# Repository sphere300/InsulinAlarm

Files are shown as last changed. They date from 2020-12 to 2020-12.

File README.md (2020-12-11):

# InsulinAlarm
A quick and dirty project to build a small device that sounds an alarm if the insulin is left out of the fridge too long.

# Part List:
* [Adafruit Trinket M0](https://www.adafruit.com/product/3500)
* [MCP9808 High Accuracy I2C Temperature Sensor Breakout Board](https://www.adafruit.com/product/1782)
* [Piezo Buzzer - PS1240] (https://www.adafruit.com/product/160)
* [Lithium Ion Polymer Battery - 3.7v 500mAh] (https://www.adafruit.com/product/1578)
* [JST-PH 2-Pin SMT Right Angle Connector] (https://www.adafruit.com/product/1769)
* Wire
* Snap Safe Safety Amber Vial 40 DR (Could be replaced with any large enough container though you would need to change one of the prints)

This project also assumes that you have a Lantus Insulin vial inside a Snap Safe Safety Amber Vial 40 DR container. The electronics can easily fit within the 40DR saftey vial with the insulin.

# Assembly Instructions:
*Desolder the DotStar LED, and the on LED.* 

With those two LEDs you are looking at a battery life with a 500 mAh battery in the neighborhood of 20 days. Without them it will last up to 347.22 days (realistically a lot less, but that's the theoretical cap with a 500 mAh battery).

The DotStar has a high idle current somewhere in the neighborhood of 1 mA. Without it and the on LED I was able to measure a standby current from the battery of 0.06 mA

I suggest you do this first as there is a very real chance you will break and destroy your Trinket M0 in the process of removing the SMT LED's. The good new is that they are cheap microcontrollers so it won't set you back much but its a tricky process. After removing the LEDs you should immediately test using a blink demo to ensure that after their removal there are no shorts and that the code is able to run.

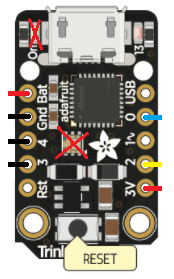
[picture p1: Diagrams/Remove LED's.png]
LED's to Remove


Once you have the LED's removed you should proceed to wire everything up:

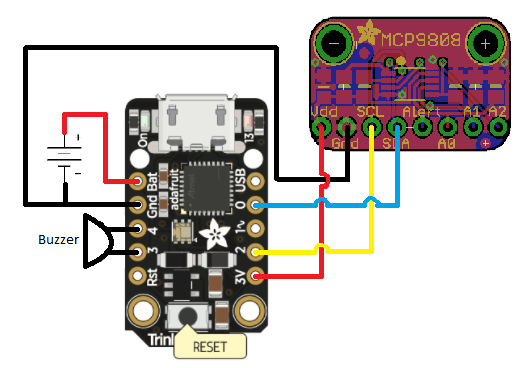
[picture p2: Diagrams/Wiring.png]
Wiring Diagram


Note in the parts list I list a 500 mAh battery but in the code I mention a 420 mAh battery that is because I used the 420 with a [JS Battery Extender Cable] (https://www.adafruit.com/product/1131) on my iteration. In retrospect the right angle JST connecter would have been better as cutting the cable and soldering a female connector to the short wire 420 mAh battery is tad fragile.

Once everything is wired you can snap it all together for something like this:

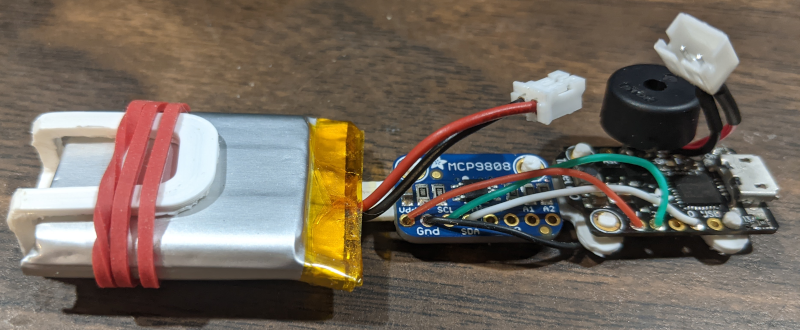
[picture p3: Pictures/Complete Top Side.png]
Finished Top Side

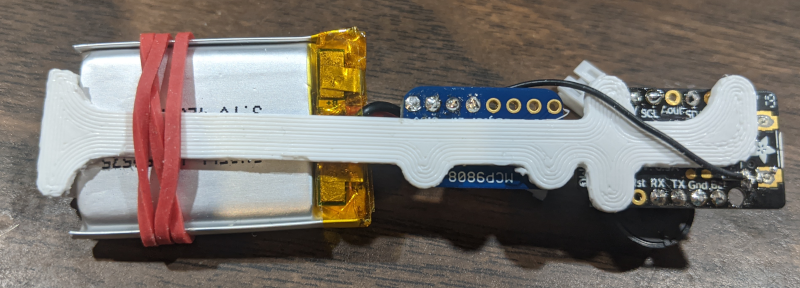
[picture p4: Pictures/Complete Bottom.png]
Finished Bottom Side


Push the assembly into the pill bottle and then put the electronics inside.

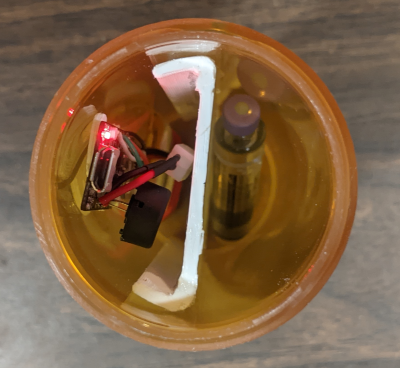
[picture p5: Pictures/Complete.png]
All Together


One last todo I may update in the coming days is to firmely attach the electronics and battery to the seperator as they move around a bit when I remove the insulin. As I mentioned in my description I recently bought the new lantus so I just wanted something quick and dirty. I am certain as I use it I will tweak and adjust this as I continue to give insulin to my cat twice daily but overal this is the first iteration of this.

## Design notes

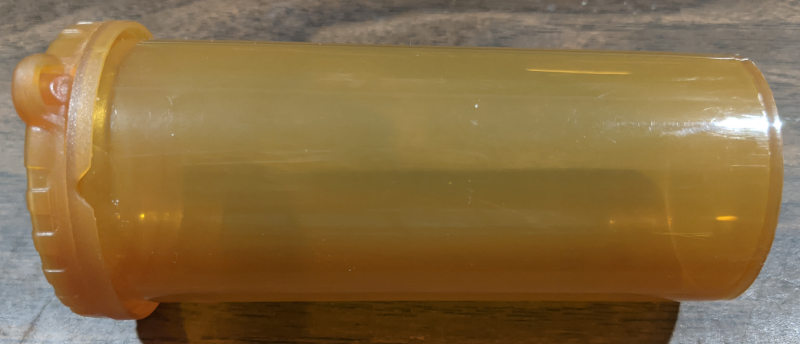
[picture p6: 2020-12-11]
Pictures/Snap Safe Safety Amber Vial.png

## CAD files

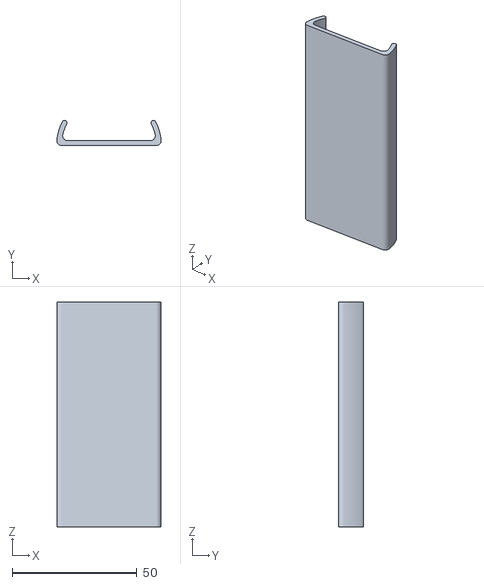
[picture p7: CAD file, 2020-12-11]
3D Models/PillBottleHolder.stl
41.8 x 10.1 x 90.0

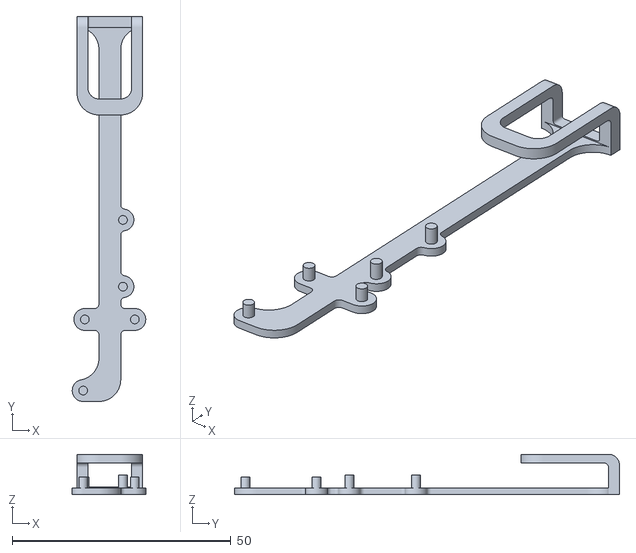
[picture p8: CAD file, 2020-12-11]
3D Models/Insulin Alarm.stl
16.8 x 88.0 x 9.25

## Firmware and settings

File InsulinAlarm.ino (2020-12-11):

/*

  Insulin Alarm Code

  This code is intended to be a very quick and dirty insulin alarm that goes off if the container it is stored in is left outside of the fridge too long. 
  
  I have a cat who is now diabetic, and after leaving the insulin out of the fridge one too many times by accident I decided to makee this alarm so that I don't need to keep buying more insulin.

  This is a very simple set of code designed to work with the adafruit trinket M0 board, a MCP9808 temperature sensor on adafruits break out board, a lithium ion battery, and a simple PS1240 Buzzer.
  
  Created by Sphere300

  Warnings and disclaimers:
  I am not an expert at firmware or hardware design and everything I do in the code and with the hardware may be flawed, so use this code and hardware at your own risk.
  
  This is a hobby project and is shared with others in case they find it useful. This code is not exensivly tested and may fail unexpectedly for any reason, 
  and as such it is NOT intended to be used in a medical setting or in any scenario where its failure may cause harm or loss of life.

  License:
  All materials for this project are released under te GNU Lesser General Public License 2.1. The Adafruit MCP9808 Library uses an MIT license and the RTCZero library is also GNU Lesser Publc license 2.1.
  You can find their work hosted in the arduino libraries or on git hub:
  https://github.com/arduino-libraries/RTCZero
  https://github.com/adafruit/Adafruit_MCP9808_Library

  This code was initially based on the SimpleRTCAlarm demo included with the RTC Libary.

  This code was created on:
  December 11 2020  
   
*/

#include <RTCZero.h>
#include "Adafruit_MCP9808.h"

Adafruit_MCP9808 tempsensor = Adafruit_MCP9808();

/* Create an rtc object */
RTCZero rtc;

//Buzzer bins
int buzzer1 = 3;
int buzzer2 = 4;

//Build in Red LED (the one we did not desolder)
int led = 13;

//Some time constants to setup the RTC
/* Change these values to set the current initial time */
const byte seconds = 0;
const byte minutes = 00;
const byte hours = 17;
/* Change these values to set the current initial date */
const byte day = 17;
const byte month = 11;
const byte year = 15;

//Track how long we have been on os we can indicate when we need to recharge the battery.
long onCount = 0;

void setup()
{
  //Indicate we are ready to program
  digitalWrite(led, HIGH);

  //Delay for 60 seconds to let us reprogram it if we need to (Standby screws up the USB avr)
  delay(60000); //Let us reprogram the board before we put the board to sleep.

  //
  digitalWrite(led, LOW);

  //Ensure we can talk to the temperature sensor
  if (!tempsensor.begin(0x18)) {
    
    //If we can't measure temperature then we are not going anywhere fast.
    while (1)
    {
      //Pulse the LED to let us know it can't talk to the Temp Sensor.
      digitalWrite(led, HIGH);
      delay(1000);
      digitalWrite(led, LOW);
      delay(1000);
    }
  }
  //Choose the fastest temperature setting with +-0.5°C in 30 ms
  tempsensor.setResolution(0); 
  //Shut it down to save power
  tempsensor.shutdown_wake(1);

  //Setup the buzzer
  pinMode(buzzer1, OUTPUT); 
  pinMode(buzzer2, OUTPUT);
  //Set the buzzer off
  digitalWrite(buzzer1, LOW);
  digitalWrite(buzzer2, LOW);
  
  //Start up the clock
  rtc.begin();
  rtc.setTime(hours, minutes, seconds); //We have no idea what the real time is ... 
  rtc.setDate(day, month, year);
  //Set the first alarm to be 1 minute from now 
  rtc.setAlarmTime(17, 05, 00);
  rtc.enableAlarm(rtc.MATCH_HHMMSS);
  rtc.attachInterrupt(alarmMatch);
  //Got to sleep.
  rtc.standbyMode();
  

}

void loop()
{
  onCount += 1;
  //Assuming a 420 mAh and based on standby consumption with the Dotstar and On LED's removed (0.06 mA) we should have an ideal longevity of about 291.7 days,
  // but we are chilling battery, it will lose power over time, and it may not be fully charged so lets turn on the low batt after 75% of the expected life or 218.75 days. 
  //The board will be asleep most of the time unless you leave it outside the fridge, so we assume that the standby dominates the power consumption. 
  //Based on that We can make an assumption that each sleep wake cycle dominates the on time. 
  //Ignoring the roughly 30ms per sleep cycle this we get 63000 cycles of 5 minute sleeps before 75% of the ideal battery life is consumed.
  if (onCount > 63000) {
    // Turn on to indicate low battery, yes it will consume power but without it we will never know when to replace the battery, and in theory you will use the insulin every day. 
    digitalWrite(led, HIGH);
  }
  
  //Wakeup the temperature sensor:
  tempsensor.wake();   // wake up, ready to read!
  //Read the temp
  float c = tempsensor.readTempC();
  while (c > 16)
  {
    //If the temp is > 16 then start buzzing. In theory it should be colder so this will turn off faster when its put back in the fridge.
    //buzz for 10 seconds
    for (int j = 0; j <= 50; j++) { //Buzz for 10 seconds.
      for (int i = 0; i <= 50; i++) {
        //Make a square wave. Set the pins to opposite values to give us a bit more sound
        digitalWrite(buzzer1, HIGH);
        digitalWrite(buzzer2, LOW);
        delay(1);               
        digitalWrite(buzzer1, LOW);
        digitalWrite(buzzer2, HIGH);
        delay(1);
      }
      for (int k = 0; k <= 100; k++) {
        //Make a higher pitched square wave
        digitalWrite(buzzer1, HIGH);
        digitalWrite(buzzer2, LOW);
        delay(0.5);
        digitalWrite(buzzer1, LOW);
        digitalWrite(buzzer2, HIGH);
        delay(0.5);
      }
    }
    //Check the temperature before we loop again.
    c = tempsensor.readTempC();
  }
  //Once the temperature drops below 16°C go back to sleep for a bit.
  tempsensor.shutdown_wake(1); // shutdown MSP9808 - power consumption ~0.1 mikro Ampere, stops temperature sampling
  //Reset the alarm for 5 minute from now. IE wakeup once every 5 minutes and check if its above temp.
  int alarmMinutes = rtc.getMinutes();
  alarmMinutes += 5;
  if (alarmMinutes >= 60) {
    alarmMinutes -= 60;
  }

  rtc.setAlarmTime(rtc.getHours(), alarmMinutes, rtc.getSeconds());
  
  rtc.standbyMode();    // Sleep until next alarm match*/
}

void alarmMatch()
{
  //We don't currently do anything in the interupt we just need it to wake from standby.
}

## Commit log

2020-12-11 First Check in, it seems to work as is. Will add instructions next.
    [Insulin Alarm.stl, PillBottleHolder.stl]
2020-12-11 Adding one more assembly Picture
